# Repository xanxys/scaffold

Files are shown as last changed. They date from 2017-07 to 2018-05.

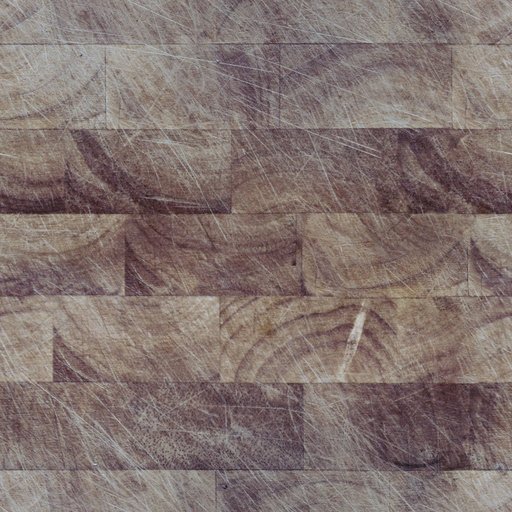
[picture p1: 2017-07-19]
overmind/texture/wood.jpg

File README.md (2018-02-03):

# scaffold

Scaffold: Progression of Rails 2017 (https://www.youtube.com/watch?v=H0F9yggMfn8 "Scaffold: Progression of Rails 2017")

* PRD: https://docs.google.com/document/d/1AyhhH3LTPeGcEkzU2smBuM1e6MzfZJXZTJ8Jl38s1jc/edit
* Designs
  * Mechanical hardware: Autodesk Fusion360 cloud
  * Electronic hardware: Google Drive / Eagle
  * Firmware: This repo
  * Softawre: This repo (`overmind/`)
* Experiments
  * TBD
* Documents: https://drive.google.com/drive/folders/0B6zCoyeuDn-pVGp6S2Y4Tmo1dEE

## Components

* worker: AVR firmware for worker PCB
* feeder: AVR firmware for rail feeder
* overmind: controls everything, via TWELITE monostick. Written in electron (desktop webapp platform).

Model names:

https://docs.google.com/document/d/1zPHIgSu1AZrwIe-akWDu8TK5ug4Fznx-tUY5lZn-zfI/edit?usp=drive_web

## Overmind

First-time only, when you cloned repo, run:
```
cd ./overmind
npm install
```

To develop / run overmind, you need two consoles.

In one, do the following to compile & setup dynamic reloader for
```
cd ./overmind
npm run dev
```

Then, in another, to start the app:
```
cd ./overmind
npm start
```

To run unit tests:
```
npm test
```

## Requirements

Re-creating

* SLA 3d printing: Form2
* PWB manufacturer: Seeed studio
* Electronic parts: All are sourceabe from digikey
* PCB reflow oven
* USBasp

## AVR Firmware writing

First time only:
```
scons writefuse
```

First time & whenever code is changed:
```
scons write-builder
```
or
```
scons write-feeder
```

Just compile and see resulting FW size:
```
scons
```

# Communication Protocol Stack

## Commands

* p: print status
* e: enqueue actions

```
Command
  = "p"
  | "e" Action+
```

```
Action = [Duration ms : 2] ([ActionTarget ASCII: 1] [ActionVal int : 1]*)*
```

e.g.
```
eA123BCD-23
```

## Addressing

Everything is in big endian.

overmind -> worker
```
Packet = [dest addr : 4] Command
```
When addr = 0xffffffff, it means broadcasting.

worker -> overmind
```
Packet = [src addr : 4] [worker timestamp in millisec : 4] [JSON ascii : N]
```

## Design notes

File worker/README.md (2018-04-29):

# Worker (Builder 2.0: S60C-TB, Feeder 1.0: S60C-FD-x)

Builder 2.0
* PCB DD & Eratta: https://docs.google.com/document/d/1Juym4ehH7gGHqDHJOSv_l-aBb0Xs5iWDp3gg6BylRzI/edit
* Designs
  * Hardware: Autodesk Fusion360 cloud
  * PCB: Eagle
    * 2.0: https://drive.google.com/file/d/0B6zCoyeuDn-pWUhYQTVqWkgwS1E/view?usp=sharing

Feeder 1.0

## Error Handling Policy

* Discrete data (command type): Ignore & warn
* Analog data (duration, pos, vel): Clip & warn

## Coordinate System

S60-TB

|Canonical | IMU |
|---|---|
| X | -Y |
| Y | X |
| Z | Z |

## Sensor Commands & Pins

|New name|ADC pin| Legacy Name | TB | FDW-RS | TB legacy commands | FDW-RS legacy commands |
|---|---|---|---|---|---|---|
| S0 | 1 |  T | rail center (+)  | port stops (-) | Tx: if S0>=x, stop MV0 | Sx: if S0<x, stop MV0 |
| S1 | 6 |  O | unused | origin (+) | | Ox: if S1>x, stop MV0 |
| S2 | 7 |  X | unused | unused | | |

polarities

* + (value is big when condition is true)
* - (value is smaller whencondition is true)

In the new scheme, polarity is baked as FW and value is negated (x := 255-x) in the worker.
Thus, only S(n)>x: stop MV(0) cutoff condition is necessary.

This command is written as "/S0>12", "/S1>200" etc in human-readable command format.
Zero or one condition can exist in an Action.

## Action human & binary format

Human readable action format:

```
Command = 'e' Action (',' Action)*

Action = (dur:Integer[1,5000]) (Target Value)+ CutoffCondition?

Target
  = 'a' | 'b'  # BT SRV
  | 't' | 'o' | 's'  # BT MV
  | 'v'  # FDW-RS MV

CutoffCondition = '/' 'S' (sensor_index:Integer[0,2]) '>' (sensor_value:Value)

Value = Integer[0, 255]
```

Binary action format:

```
Command = 'e' (num_actions: Uint8) Action+

Action = (dur:Uint16be) (numTVs:Uint7) (numCutoff:Uint1) (Target:Uint8 value:Uint8)+ CutoffCondition?

CutoffCondition = (sensor_index:Uint8) (sensor_value:Uint8)
```

## Builder Pin assigment / connections (V2)
ATmega328P

16MHz (ceralock) / 1:1 clock division / No watchdog

|pin|usage|
|---|---|
|PB0| - |
|PB1| - |
|PB2| - |
|PB3/OC2A| ISP MOSI / PWMA  |
|PB4| ISP MISO  |
|PB5| ISP SCK  |
|PB6| XTAL1  |
|PB7| XTAL2  |
| |  |
| |  |
|PC0| red indicator LED  |
|PC1/ADC1| SEN-T  |
|PC2| -  |
|PC3| -  |
|PC4| I2C-SDA  |
|PC5| I2C-SCL  |
|PC6| #RESET  |
|PC7| -  |
| |  |
| |  |
|ADC6| SEN-O (rail marker)  |
|ADC7| Rail Sensor  |
| |  |
| |  |
|PD0| TWELITE-RX  |
|PD1| TWELITE-TX  |
|PD2| -  |
|PD3/OC2B| PWMB  |
|PD4| - |
|PD5| - |
|PD6| - |
|PD7| - |

### Extension head

A(right): screw rack

B(left): dump

### I2C bus

DRV8830 (1/3)

* OUT: Train motor
* Addr[3:0]: 0000 (A0: L, A1: L)

DRV8830 (2/3)

* OUT: Orientor motor
* Addr[3:0]: 0001 (A0: open, A1: L)

DRV8830 (3/3)

* OUT: Extension motor (screw)
* Addr[3:0]: 0010 (A0: H, A1: L)

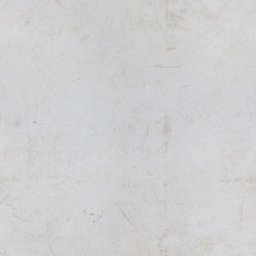
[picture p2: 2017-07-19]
overmind/texture/plastic.jpg

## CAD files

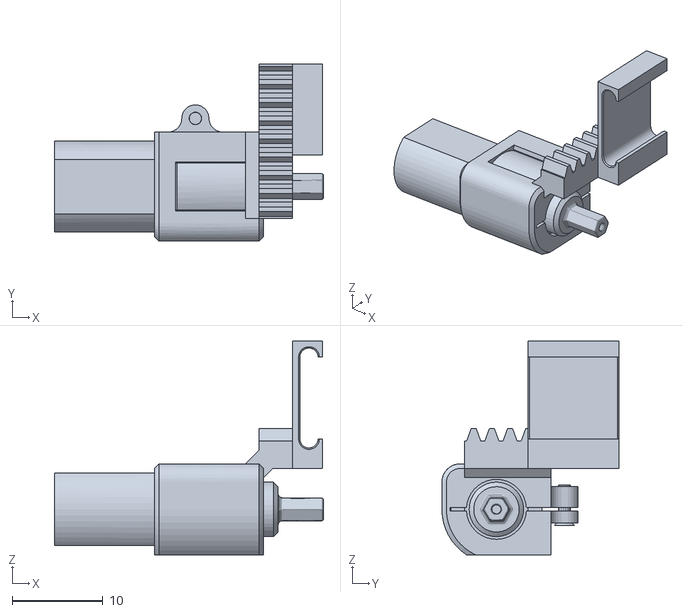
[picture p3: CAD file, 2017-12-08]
overmind/models/S60C-TB_mhead.stl
29.6 x 19.5 x 23.5

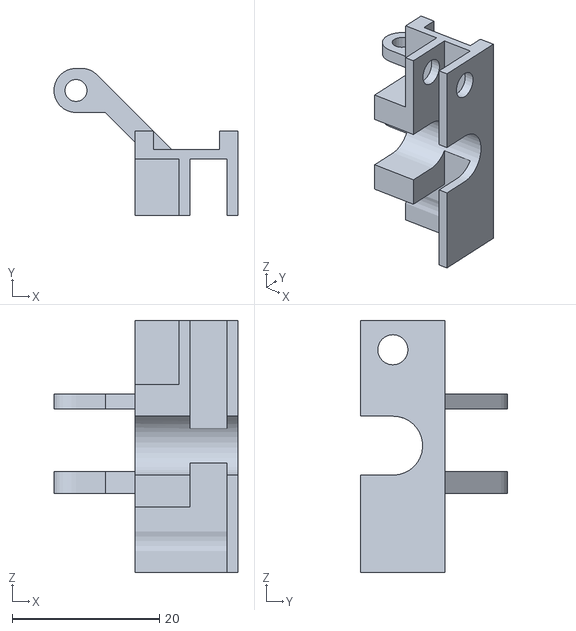
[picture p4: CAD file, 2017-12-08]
overmind/models/S60C-TB_darm.stl
25.0 x 20.0 x 34.2

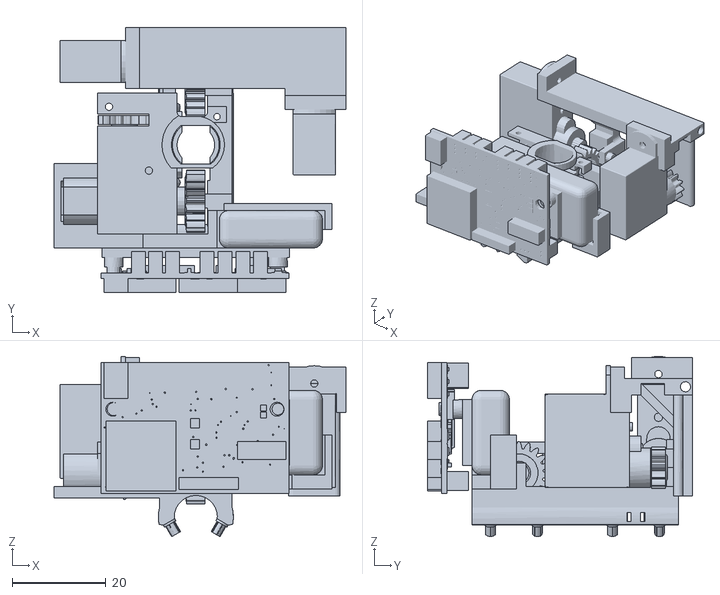
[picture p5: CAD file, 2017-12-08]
overmind/models/S60C-TB.stl
62.2 x 56.5 x 38.5

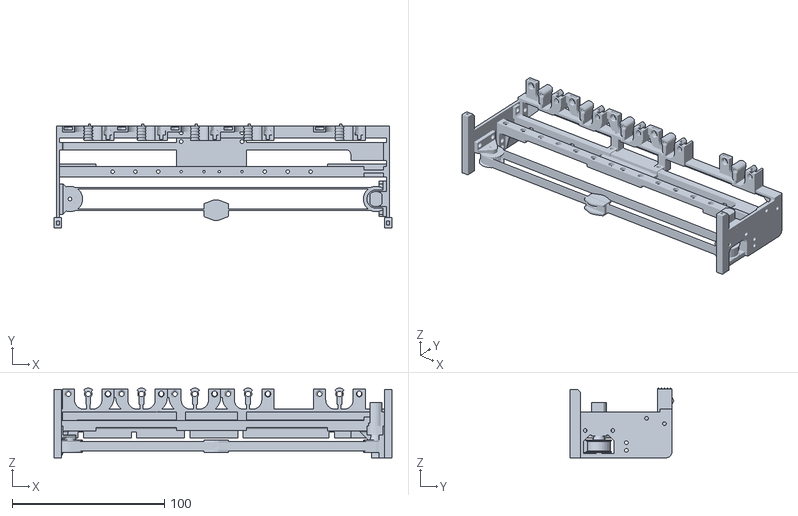
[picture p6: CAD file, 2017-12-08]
overmind/models/S60C-FDW-RS_fixed.stl
222.0 x 68.2 x 45.9

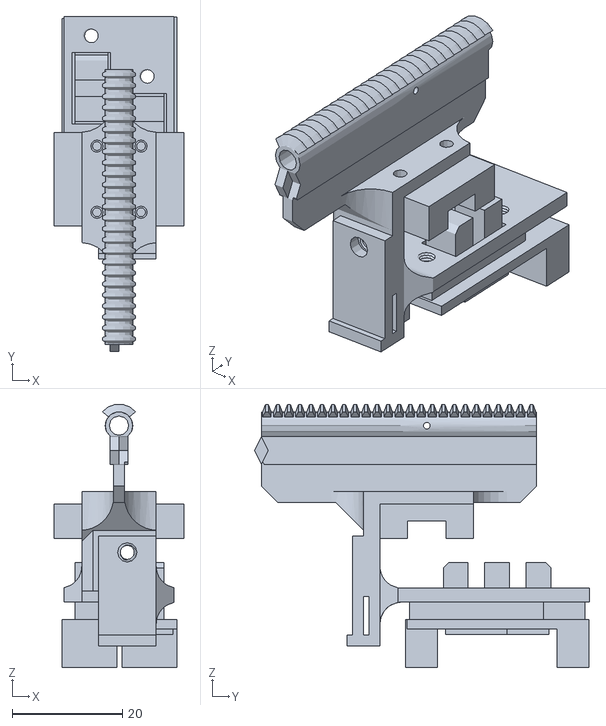
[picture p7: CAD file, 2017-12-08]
overmind/models/S60C-FDW-RS_stage.stl
23.5 x 60.8 x 47.7

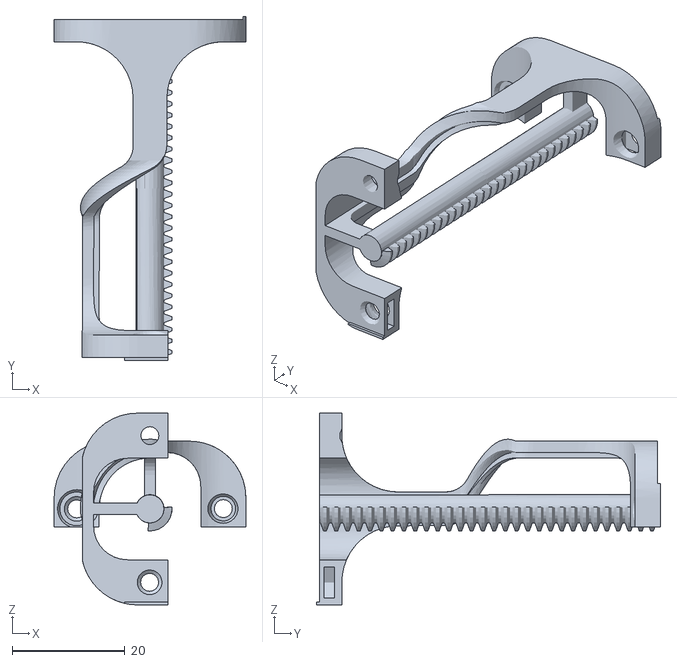
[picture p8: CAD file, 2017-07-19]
overmind/models/S60C-RH.stl
34.0 x 61.0 x 34.0

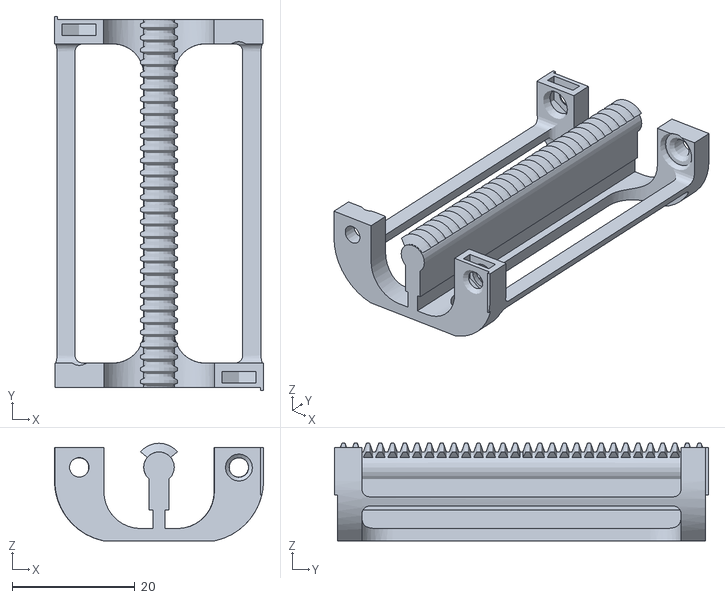
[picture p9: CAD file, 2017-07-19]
overmind/models/S60C-RS.stl
34.0 x 61.0 x 15.9

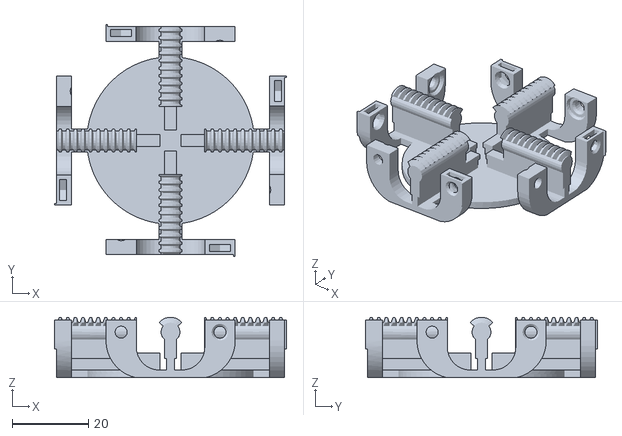
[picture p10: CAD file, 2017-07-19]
overmind/models/S60C-RR.stl
61.0 x 61.0 x 15.9

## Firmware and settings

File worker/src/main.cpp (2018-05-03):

#include <Arduino.h>
#include <MsTimer2.h>
#include <nanopb/pb_decode.h>
#include <nanopb/pb_encode.h>
#include <proto/builder.pb.h>

#include "action.hpp"
#include "shared_state.h"

ActionExecutorSingleton g_actions;

int16_t convert_acc(int16_t raw) {
  return (static_cast<int32_t>(raw) * 61) / 1000;
}

void fill_sensor_status(SensorStatus& status) {
  // TODO: scaling
  status.gyro_x_cdps = -imu.gyro[1];
  status.gyro_y_cdps = imu.gyro[0];
  status.gyro_z_cdps = imu.gyro[2];

  // status.acc_x_mg = convert_acc(-imu.acc[1]);
  // status.acc_y_mg = convert_acc(imu.acc[0]);
  // status.acc_z_mg = convert_acc(imu.acc[2]);
  status.acc_x_mg = odometry.vx;
 // status.acc_y_mg = odometry.rot;
  status.acc_z_mg = 0;

  status.optical_rail = sensor.get_sensor2();
  status.odometry_rail = odometry.get_rot();
}

class CommandHandler {
 private:
  MaybeSlice datagram;  // dependent on buffer inside twelite.
  int r_ix;

  uint8_t buffer[80];

 public:
  CommandHandler(MaybeSlice datagram) : datagram(datagram), r_ix(0) {}

  void handle() {
    r_ix = 0;
    indicator.flash_blocking();
    uint8_t code = read();
    switch (code) {
      case CommandType_PRINT_STATUS:
        exec_print();
        break;
      case CommandType_SCAN_I2C:
        exec_scan();
        break;
      case CommandType_ENQUEUE:
        exec_enqueue();
        break;
      case CommandType_READ_SENSOR:
        exec_read_sensor();
        break;
      default:
        TWELITE_ERROR(Cause_OVERMIND);  // unknown command
        break;
    }
  }

 private:
  // Consume next byte if it matches target (return true).
  // If it doesn't match, doesn't consume anything (return false).
  bool consume(char target) {
    if (r_ix < datagram.size) {
      if (datagram.ptr[r_ix] == target) {
        r_ix++;
        return true;
      }
    }
    return false;
  }

  char peek() {
    if (r_ix < datagram.size) {
      return datagram.ptr[r_ix];
    } else {
      return 0;
    }
  }

  bool available() { return r_ix < datagram.size; }

  char read() {
    if (r_ix < datagram.size) {
      char ret = datagram.ptr[r_ix];
      r_ix++;
      return ret;
    } else {
      return 0;
    }
  }

  void unread(char c) {
    if (r_ix > 0) {
      r_ix--;
    }
  }

  int16_t parse_int() {
    bool positive = !consume('-');
    int16_t v = 0;
    while (available()) {
      char c = read();
      if ('0' <= c && c <= '9') {
        v = v * 10 + (c - '0');
      } else {
        unread(c);
        break;
      }
    }
    return positive ? v : -v;
  }

 private:  // Command Handler
  void exec_enqueue() {
    while (true) {
      enqueue_single_action();
      if (!consume(',')) {
        break;
      }
    }
    TWELITE_INFO();  // Enqueue executed.
  }

  void exec_print() {
    {
      Status status;
      g_actions.fill_status(status);

      buffer[0] = PacketType_STATUS;
      pb_ostream_t stream =
          pb_ostream_from_buffer((pb_byte_t*)(buffer + 1), sizeof(buffer) - 1);
      if (pb_encode(&stream, Status_fields, &status)) {
        twelite.send_datagram(buffer, 1 + stream.bytes_written);
      } else {
        TWELITE_ERROR(Cause_LOGIC_RT);
      }
    }
    delay(10);
    {
      IOStatus status;
      fill_io_status(status);

      buffer[0] = PacketType_IO_STATUS;
      pb_ostream_t stream =
          pb_ostream_from_buffer((pb_byte_t*)(buffer + 1), sizeof(buffer) - 1);
      if (pb_encode(&stream, IOStatus_fields, &status)) {
        twelite.send_datagram(buffer, 1 + stream.bytes_written);
      } else {
        TWELITE_ERROR(Cause_LOGIC_RT);
      }
    }
  }

  void exec_read_sensor() {
    ReadSensorCommand command;
    pb_istream_t stream =
        pb_istream_from_buffer(datagram.ptr + 1, datagram.size - 1);
    if (!pb_decode(&stream, ReadSensorCommand_fields, &command)) {
      TWELITE_ERROR(Cause_OVERMIND);  // unparsable
      return;
    }

    // TODO: Read value.
    g_async_sensor_ttl_ms = 5000;  // command.verbose_sensor_ttl_ms;
    g_async_sensor_since_last_sent_ms = 0;
  }

  void exec_scan() {
    I2CScanResult result;
    g_actions.fill_i2c_scan_result(result);

    buffer[0] = PacketType_I2C_SCAN_RESULT;
    pb_ostream_t stream =
        pb_ostream_from_buffer((pb_byte_t*)(buffer + 1), sizeof(buffer) - 1);
    if (pb_encode(&stream, I2CScanResult_fields, &result)) {
      twelite.send_datagram(buffer, 1 + stream.bytes_written);
    } else {
      TWELITE_ERROR(Cause_LOGIC_RT);
    }
  }

  void enqueue_single_action() {
    int16_t dur_ms = parse_int();
    if (dur_ms < 1) {
      dur_ms = 1;
      TWELITE_ERROR(Cause_OVERMIND);  // dur capped to 1ms
    } else if (dur_ms > 5000) {
      dur_ms = 5000;
      TWELITE_ERROR(Cause_OVERMIND);  // dur capped to 5s
    }
    Action action(dur_ms);

    while (true) {
      char target = read();
      switch (target) {
        case '!':
          // action.report = true;
          break;
        case 'a':
          action.servo_pos[CIX_A] = safe_read_pos();
          break;
        case 'b':
          action.servo_pos[CIX_B] = safe_read_pos();
          break;
        case 't':
          action.motor_vel[MV_TRAIN] = safe_read_vel();
          break;
        case 'o':
          action.motor_vel[MV_ORI] = safe_read_vel();
          break;
        case 's':
          action.motor_vel[MV_SCREW_DRIVER] = safe_read_vel();
          break;
        case 'T':
          action.train_cutoff_thresh = safe_read_thresh();
          break;
        default:
          TWELITE_ERROR(Cause_OVERMIND);  // unknown action target
      }

      char next = peek();
      if (next == 0 || next == ',') {
        break;
      }
    }
    g_actions.enqueue(action);
  }

  uint8_t safe_read_thresh() {
    int16_t value = parse_int();
    if (value < 0) {
      value = 0;
      TWELITE_ERROR(Cause_OVERMIND);  // too small value
    } else if (value > 255) {
      value = 255;
      TWELITE_ERROR(Cause_OVERMIND);  // too big value
    }
    return value;
  }

  uint8_t safe_read_pos() {
    int16_t value = parse_int();
    if (value < 10) {
      value = 10;
      TWELITE_ERROR(Cause_OVERMIND);  // too small pos
    } else if (value > 33) {
      // note: 255 is reserved as SERVO_POS_KEEP.
      value = 33;
      TWELITE_ERROR(Cause_OVERMIND);  // too big pos
    }
    return value;
  }

  int8_t safe_read_vel() {
    int16_t value = parse_int();
    if (value < -127) {
      value = -127;
      TWELITE_ERROR(Cause_OVERMIND);  // too small vel
    } else if (value > 127) {
      value = 127;
      TWELITE_ERROR(Cause_OVERMIND);  // too big vel
    }
    return value;
  }

  void fill_io_status(IOStatus& status) const {
    fill_sensor_status(status.sensor);
    g_actions.fill_output_status(status.output);
  }
};

constexpr uint8_t IMU_POLL_CYCLE = 19;
uint8_t imu_poll_index = 0;

void loop1ms() {
  g_actions.loop1ms();

  uint16_t ttl_ms = g_async_sensor_ttl_ms;
  if (ttl_ms > 0) {
    ttl_ms--;
  }
  g_async_sensor_ttl_ms = ttl_ms;
  g_async_sensor_since_last_sent_ms++;

  if (imu_poll_index == 0) {
    imu.poll();
    odometry.poll();
  }
  imu_poll_index++;
  if (imu_poll_index >= IMU_POLL_CYCLE) {
    imu_poll_index = 0;
  }
}

int main() {
  //// Minimum AVR & 3.3V (TWELITE) init.
  // Init arduino core things (e.g. Timer0).
  init();
  twelite.init();
  indicator.flash_blocking();
  TWELITE_INFO();  // Minimum HW initialized.

  //// Enable 5V & peripherals.
  set_5v_power(true);
  delay(50);  // IMU(20ms), 5V DC/DC (?ms)

  // Init I2C bus.
  I2c.begin();
  I2c.pullup(0);  // we use external pullup registers
  I2c.timeOut(10);

  // Start 6-axis sensor.
  imu.init();

  // Start odometry magnetic sensor.
  odometry.init();

  indicator.flash_blocking();
  TWELITE_INFO();  // All HW initialized.

  g_actions.init();
  // Initialize servo pos to safe (i.e. not colliding with rail) position.
  {
    Action action(1 /* dur_ms */);
    action.servo_pos[CIX_A] = 13;
    action.servo_pos[CIX_B] = 11;
    g_actions.enqueue(action);
  }

  // Fully initialized. Start realtime periodic process & idle tasks.
  setMillisHook(loop1ms);
  while (true) {
    if (g_twelite_packet_recv_done) {
      MaybeSlice datagram = twelite.get_datagram();
      if (datagram.is_valid()) {
        CommandHandler command_handler(datagram);
        command_handler.handle();
      }
      twelite.restart_recv();
    }
    if (g_async_message_avail) {
    }
    if (g_async_sensor_ttl_ms > 0 && g_async_sensor_since_last_sent_ms > 100) {
      IOStatus status;
      status.output = OutputStatus_init_default;
      fill_sensor_status(status.sensor);

      uint8_t buffer[80];
      buffer[0] = PacketType_IO_STATUS;
      pb_ostream_t stream =
          pb_ostream_from_buffer((pb_byte_t*)(buffer + 1), sizeof(buffer) - 1);
      if (pb_encode(&stream, IOStatus_fields, &status)) {
        twelite.send_datagram(buffer, 1 + stream.bytes_written);
      } else {
        TWELITE_ERROR(Cause_LOGIC_RT);
      }

      g_async_sensor_since_last_sent_ms = 0;
    }
  }
}

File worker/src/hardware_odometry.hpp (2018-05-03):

#pragma once

#include <I2C.h>

/**
 * Driver for MLX90393 magnetic sensor, which is coupled to measure main axis
 * gear rotation. ds:
 * https://cdn.sparkfun.com/assets/learn_tutorials/5/7/7/MLX90393-Datasheet-Melexis.PDF
 *
 * sample code:
 * https://github.com/ControlEverythingCommunity/MLX90393/blob/master/Arduino/MLX90393.ino
 */
class Odometry {
 private:
  constexpr static uint8_t addr =
      20;  // designed to be 0x0c, but somehow ended up being 20.

  // Commands
  constexpr static uint8_t WRITE_REGISTER = 0x60;

  constexpr static uint8_t STATUS_BURST_MODE = _BV(7);
  constexpr static uint8_t STATUS_ERROR = _BV(4);

  struct __attribute__((__packed__)) U16Be {
    uint8_t h;
    uint8_t l;
  };

  struct __attribute__((__packed__)) ReadMeasurementResult {
    uint8_t status;
    U16Be x, y, z;
  };

  /**
   * These constants are generated by following python code:
   *
   * COS: python -c "import math; print [int(math.cos(i/128.0*math.pi)*255) for
   * i in range(64)]" SIN: python -c "import math; print
   * [int(math.sin(i/128.0*math.pi)*255) for i in range(64)]"
   */
  static constexpr uint8_t QUAD_ANGLE = 64;
  const uint8_t QUAD_COS[QUAD_ANGLE] = {
      255, 254, 254, 254, 253, 253, 252, 251, 250, 248, 247, 245, 244,
      242, 240, 237, 235, 233, 230, 227, 224, 221, 218, 215, 212, 208,
      204, 201, 197, 193, 188, 184, 180, 175, 171, 166, 161, 156, 151,
      146, 141, 136, 131, 125, 120, 114, 109, 103, 97,  91,  85,  79,
      74,  68,  61,  55,  49,  43,  37,  31,  24,  18,  12,  6};

  const uint8_t QUAD_SIN[QUAD_ANGLE] = {
      0,   6,   12,  18,  24,  31,  37,  43,  49,  55,  61,  68,  74,
      79,  85,  91,  97,  103, 109, 114, 120, 125, 131, 136, 141, 146,
      151, 156, 161, 166, 171, 175, 180, 184, 188, 193, 197, 201, 204,
      208, 212, 215, 218, 221, 224, 227, 230, 233, 235, 237, 240, 242,
      244, 245, 247, 248, 250, 251, 252, 253, 253, 254, 254, 254};

 public:
  bool init_success = false;
  int16_t vx = 0;
  int16_t vy = 0;

  // As seen from X+, CCW is positive (=forward)
  uint8_t angle = 0;
  int8_t num_rot = 0;

  void init() {
    // Reset command.
    // I2c.write(addr, (uint8_t)0xf0);
    // delay(10);

    // Set RES{x,y,z} = 2, OSR=0, DIG_FILT=0
    write_reg(2, 0b101010 << 5);

    // COMM_MODE=I2C (0b11), BURST_DATE_RATE=1
    write_reg(1, (0b11 << 13) | 1);

    // GAIN=5, HALL_PLATE=0xc (default)
    write_reg(0, 0x5c);

    // Enter "Burst Mode", with measurement in all magnetic channels (Z, Y, X).
    //  I2c.write(addr, (uint8_t)0x1e);
    init_success = true;
    return;

    uint8_t status;
    uint8_t code = I2c.read(addr, 0x1e, (uint8_t)1, &status);
    vx = status + 1000;

    if ((status & STATUS_BURST_MODE) && !(status & STATUS_ERROR)) {
      init_success = true;
    }
  }

  void poll() {
    if (!init_success) {
      return;
    }
    uint8_t status;
    uint8_t code = I2c.read(addr, 0x3e, (uint8_t)1, &status);
    if (code != 0) {
      vx = 1000 + code;
      return;
    }
    if (status & STATUS_ERROR) {
      vx = 2000 + status;
      return;
    }
    delay(100);

    // Read measurement command
    I2c.write(addr, (uint8_t)0x4e);

    ReadMeasurementResult result;
    code = I2c.read(addr, 7, reinterpret_cast<uint8_t*>(&result));
    if (code != 0) {
      vx = 3000 + code;
      return;
    }
    if (result.status & STATUS_ERROR) {
      vx = 4000 + result.status;
      return;
    }
    // Expecting 6B data. -> must be 2 (2x2 + 2 = 6)
    if (result.status & 3 != 2) {
      vx = 5001;
      return;
    }
    vx = decode_value(result.x);
    vy = decode_value(result.y);
    const uint8_t new_angle = 256 - atan2(vx >> 8, vy >> 8);  // convert from sensor coords to human coords.
    const uint8_t delta = new_angle - angle;
    if (delta < 128) {
      // real angle increased
      if (new_angle < angle) {
        num_rot++;  // overflown
      }
    } else {
      // real angle decreased
      if (new_angle > angle) {
        num_rot--;  // underflown
      }
    }
    angle = new_angle;
  }

  int16_t get_rot() const { return ((int16_t)num_rot) * 256 + angle; }

 private:
  void write_reg(uint8_t mem_addr, uint16_t val) {
    uint8_t command[3];
    command[0] = val >> 8;
    command[1] = val & 0xff;
    command[2] = mem_addr << 2;
    I2c.write(addr, WRITE_REGISTER, command, (uint8_t)sizeof(command));

    uint8_t status;
    I2c.read(addr, 1, &status);
  }

  int16_t decode_value(const U16Be& v) {
    uint16_t temp = (((uint16_t)v.h) << 8) + v.l;
    if (temp > 0x8000) {
      return temp - 0x8000;
    } else {
      return -(0x8000 - temp);
    }
  }

  // Returns angle of vector (x, y), in [0, 256).
  // angle will be down-rounded.
  uint8_t atan2(int8_t x, int8_t y) const {
    if (y >= 0) {
      return x >= 0 ? atan2_quad(x, y) : atan2_quad(y, -x) + QUAD_ANGLE;
    } else {
      return x >= 0 ? (atan2_quad(-y, x) + QUAD_ANGLE * 3)
                    : (atan2_quad(-x, -y) + QUAD_ANGLE * 2);
    }
  }
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

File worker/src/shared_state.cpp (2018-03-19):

#include "shared_state.h"

Indicator indicator;
TweliteInterface twelite;
IMU imu;
DCMotor motor_screw(98);
MultiplexedSensor sensor;
Odometry odometry;

volatile bool g_twelite_packet_recv_done = false;
volatile bool g_async_message_avail = false;
volatile uint16_t g_async_sensor_ttl_ms = 0;
volatile uint16_t g_async_sensor_since_last_sent_ms = 0;

void set_5v_power(bool enabled) {
  const uint8_t EN5V = _BV(0);

  if (enabled) {
    PORTB |= EN5V;
  } else {
    PORTB &= ~EN5V;
  }
}

Indicator::Indicator() { DDRC |= _BV(PC0); }

void Indicator::flash_blocking() {
  PORTC |= _BV(PC0);
  delay(50);
  PORTC &= ~_BV(PC0);
  apply_error();
}

void Indicator::enter_error() {
  error = true;
  apply_error();
}

void Indicator::apply_error() {
  if (error) {
    PORTC |= _BV(PC0);
  } else {
    PORTC &= ~_BV(PC0);
  }
}

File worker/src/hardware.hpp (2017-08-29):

#pragma once
/* Hardware usage
* Timer0: system clock
* Timer1: action loop
* Timer2: Servo PWM
*/

#include <stdint.h>

#include "hardware_twelite.hpp"


class Indicator {
private:
  bool error;
public:
  Indicator() {
    DDRC |= _BV(PC0);
  }

  void flash_blocking() {
    PORTC |= _BV(PC0);
    delay(50);
    PORTC &= ~_BV(PC0);
    apply_error();
  }

  void enter_error() {
    error = true;
    apply_error();
  }
private:
  void apply_error() {
    if (error) {
      PORTC |= _BV(PC0);
    } else {
      PORTC &= ~_BV(PC0);
    }
  }
};

Indicator indicator;

// Perodically measure fixed number of ADC inputs & controls sensor multiplexing.
// Each phase is 2ms.
//
class MultiplexedSensor {
private:
  // Sensor channels.
  static const uint8_t I_BAT = 2;
  static const uint8_t I_SEN_T = 1;
  static const uint8_t I_SEN_O = 6;
  static const uint8_t I_SEN_X = 7;
  static const uint8_t I_INTERNAL_1V1REF = _BV(MUX3) | _BV(MUX2) | _BV(MUX1);

  // Phase definitions.
  const static uint8_t PHASE_SEN_T = 0;
  const static uint8_t PHASE_SEN_O = 1;
  const static uint8_t PHASE_SEN_X = 2;
  const static uint8_t PHASE_AVCC = 3;
  const static uint8_t PHASE_BAT = 4;
  const static uint8_t NUM_PHASES = 5;

  uint8_t current_phase;
  uint8_t phase_index;
  const static uint8_t phase_length = 2;

  uint16_t value_cache[NUM_PHASES];
public:
  MultiplexedSensor() : current_phase(PHASE_SEN_T), phase_index(0) {
  }

  void loop1ms() {
    phase_index++;
    if (phase_index == 1) {
      on_phase_middle();
    } else if (phase_index >= phase_length) {
      on_phase_end();

      phase_index = 0;
      current_phase = (current_phase + 1) % NUM_PHASES;
      on_phase_begin();
    }
  }

  // 0: 0V, 255: 5V ("max")
  uint8_t get_sensor_t() const {
    return value_cache[PHASE_SEN_T] >> 2;
  }

  uint8_t get_sensor_o() const {
    return value_cache[PHASE_SEN_O] >> 2;
  }

  uint8_t get_sensor_x() const {
    return value_cache[PHASE_SEN_X] >> 2;
  }

  uint16_t get_bat_mv() const {
    uint32_t t = value_cache[PHASE_BAT] * 5000L;
    t /= 1024L;
    return t;
  }

  uint16_t get_vcc_mv() const {
    uint32_t result = value_cache[PHASE_AVCC];
    result = (1024L * 1100L) / result; // Back-calculate AVcc in mV
    return result;
  }

  uint8_t get_rate_ms() const {
    return NUM_PHASES * phase_length;
  }

  bool is_start() const {
    return phase_index == 0 && current_phase == 0;
  }
private:
  void on_phase_begin() {
    // Connect AVcc to Vref.
    ADMUX = _BV(REFS0);

    switch (current_phase) {
      case PHASE_SEN_T:
        ADMUX |= I_SEN_T;
        break;
      case PHASE_SEN_O:
        ADMUX |= I_SEN_O;
        break;
      case PHASE_SEN_X:
        ADMUX |= I_SEN_X;
        break;
      case PHASE_AVCC:
        ADMUX |= I_INTERNAL_1V1REF;
      case PHASE_BAT:
        ADMUX |= I_BAT;
        break;
    }
  }

  void on_phase_middle() {
    // Start AD conversion.
    ADCSRA |= _BV(ADSC);
  }

  void on_phase_end() {
    if (!bit_is_set(ADCSRA, ADSC)) {
      // ADCL needs to be read first to ensure consistency.
      value_cache[current_phase] = ADCL;
      value_cache[current_phase] |= ADCH << 8;
    }
  }
};

class DCMotor {
private:
  // 7-bit address (common for read & write, MSB is 0)
  const uint8_t i2c_addr7b;
public:
  DCMotor(uint8_t i2c_addr) : i2c_addr7b(i2c_addr >> 1) {
  }

  void set_velocity(int8_t speed) {
    uint8_t abs_speed = (speed > 0) ? speed : (-speed);
    uint8_t value;
    if (abs_speed < 3) {  // 1,2 corresponds to RESERVED VSET value.
      value = 3;  // brake
    } else {
      value = (speed > 0) ? 2 : 1;  // fwd : bwd

      // abs_speed: 0sss ssss
      // value: ssss ssXX (XX=direction)
      value |= ((abs_speed << 1) & 0xfc);  // adjust scale & throw away lower 2 bits
    }

    sei();  // w/o this, TWI gets stuck after sending start condtion.
    Wire.beginTransmission(i2c_addr7b);
    Wire.write(0);  // CONTROL register
    Wire.write((byte)value);
    uint8_t res = Wire.endTransmission();
    cli();

    if (res != 0) {
      indicator.enter_error();
      twelite.warn("I2C failed");
    }
  }
};

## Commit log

2017-04-25 Please arduino ide.
2017-04-27 Queue print command.
2017-04-28 Fix very short action. Much better queue printing.
2017-04-28 Fix KEEP printing.
2017-04-29 Implement own servo / DC PWM to ix jumpiness of Servo.write output duty ratio.
2017-04-29 Fix DC motor CCW & stop.
2017-04-29 Fix PWM
2017-04-29 Adjust servo initial pos.
2017-05-04 Update pin assignment for servos.
2017-05-05 Add pin assignments to README.
2017-05-05 Rewrite DC motors to use I2C instead of timer-based PWM.
2017-05-05 Fix i2c speed & address.
2017-05-05 Add I2C result check.
2017-05-05 Add sensor read command (r).
2017-05-05 Fix servo pin assignment.
2017-05-06 Swap servo indices to match physical layer.
2017-05-21 Make things compilable without arduino IDE.
2017-05-21 Add command to write fuse for 16MHz.
2017-05-21 Update pin assignments.
2017-05-21 Add arduino initializer and LED ticking test.
2017-05-28 Half-duplex command proxy. DC motors working.
2017-05-28 Better pin table
2017-06-06 Add hack to reduce servo vibration at stasis. (to about 20% of cases, from 90%+)
    [action.hpp, hardware.hpp, main.cpp]
2017-06-06 Fundametally fix servo vibration by reducing PWM frequency.
    [action.hpp, main.cpp]
2017-06-17 Fix initial servo position.
    [action.hpp, main.cpp]
2017-06-17 Shorthand commands for extending.
    [main.cpp]
2017-06-18 Remove legacy arduino worker.
2017-06-18 Command for unfastening. Fix driver disengage (z5).
    [main.cpp]
2017-06-18 Richer status including voltage & uptime.
2017-06-20 Add pins for sensor illuminator
2017-06-21 Sensor alternating illuminators
2017-06-21 Sensor multipler. Readouts are working as intended on the rail.
2017-06-22 Delte no longer working read sensor command.
    [main.cpp]
2017-06-24 Increase driver pull robusetness.
2017-07-19 Mock overmind UI for left pane.
    [S60C-RH.stl, S60C-RR.stl, S60C-RS.stl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]
2017-07-19 Add scaffold CAD model loaders.
2017-07-19 Rail extension mock.
2017-08-06 Fix arduino header path (for Fedora26)
2017-08-06 Update pin assignments for V2.
2017-08-06 Use native PWM in V2.
2017-08-08 Succesful bidir wireless comm.
2017-08-11 Fix some leftover command validator.
    [main.cpp]
2017-08-12 Fix PWMA init
2017-08-12 Set emprically determined servo PWM range.
2017-08-13 Stabilize servos by increasing duration.
    [action.hpp, main.cpp]
2017-08-13 Update sensors to reflect new mapping & include BAT measurement.
2017-08-17 Fix loop freq & DM index.
    [main.cpp]
2017-08-17 Work around I2C address change for S-axis.
2017-08-19 Remove checksum correctly when parsing command.
    [main.cpp]
2017-08-27 Add sensor reading reporting.
2017-08-28 Fix async reporting & remove concept of step and always ms as time unit.
    [action.hpp, main.cpp]
2017-08-28 Show sensor measured values as line graph.
2017-08-29 Implement sensor finding action.
2017-08-29 Fix broken cache log. Remove hack to determine payload type.
    [action.hpp, main.cpp]
2017-08-29 Fix parse_int bug that accidentally appends 0.
    [main.cpp]
2017-08-29 Add find origin button.
2017-08-29 Don't print succesful messages.
2017-08-29 Add battery indicator.
2017-08-29 Fix / handle command buffer overflow properly.
    [main.cpp]
2017-08-29 Pretty stable extend/shorten ops with single button click.
    [action.hpp, main.cpp]
2017-09-01 Panel switching with animation.
2017-09-02 Fix unique id retrieval.
    [main.cpp]
2017-09-03 Freeup timer1
2017-09-03 Add material card finish.
2017-09-09 Update feeder pin assignmnet doc.
2017-09-09 Support stepper motor in feeder.
2017-09-20 Add sensor reactive command V to feeder FW.
2017-09-20 Implement R/C-axis in fedder and provide UI buttons.
2017-09-23 Fix spacing in multi-card case.
2017-10-12 Cleanup worker card command buttons.
2017-10-15 Fix button interferences.
2017-11-19 Add FDW-RS model.
    [S60C-FDW-RS.stl]
2017-11-19 Fix FDW CAD model alignment.
2017-11-20 Support all rail types.
2017-11-21 Fix WorldView buttons.
2017-11-30 Implement remove rail button
2017-12-04 Fix timestamp N/A & sensor reading graphs
2017-12-07 Use orthographic camera
2017-12-08 Replace FDW-RS with composite models
    [S60C-FDW-RS.stl, S60C-FDW-RS_fixed.stl, S60C-FDW-RS_stage.stl]
2017-12-08 Add S60C-TB composite model
    [S60C-TB_darm.stl, S60C-TB_fixed.stl, S60C-TB_mhead.stl]
2017-12-09 Move STL loading from view to ScaffoldModel
    [S60C-FDW-RS.stl, S60C-T.stl, S60C-TB.stl]
2017-12-10 Update FD firmware to support two sensors
2017-12-10 Fix sensor commands for FDW-RS
    [action.hpp, main.cpp]
2017-12-10 Update sensor status message
2017-12-10 Put succesful twice. HW modif: Extend DRV & Rotate DARM SERVO CCW (seen from left) and fix tightly
2017-12-11 Add show future button
2017-12-11 Fix semantics of model init button
2017-12-11 Implement ScaffoldModel switching
2017-12-17 "Fix" setTimeout -> Timer cast
2017-12-17 Refine TB commands according to 6mm driver
2017-12-17 Fix FDW-RS param-stagePos bidir mapping
2017-12-18 Fix stage anim
2017-12-20 FDW-RS stagePos editing
2017-12-20 Couple TB to FDW stage
2018-02-04 Use better I2C library
2018-02-04 I2C bus scanning
2018-02-04 Restructure hardwares. IMU init sequence.
2018-02-04 Gyro X readings (seemingly correct)
2018-02-04 Update IMU polling code
2018-02-04 Fix I2C address
2018-02-04 Extend IMU
2018-02-04 Report IMU values
2018-02-05 Try I2CScanResult in proto3
2018-02-05 I2CScanResult became 49B (json) -> 5B(tag+proto). Beware of stack size, buffer[200] crashes command loop.
    [action.hpp, main.cpp]
2018-02-06 Make device scan faster
2018-02-06 More reliable status print
2018-02-07 Get rid of arduino useless code and TWELITE recv w/ async
2018-02-07 Fix critical bug (non-volatile state ends up deleting everything in optimization)
    [main.cpp]
2018-02-07 Further minification of arduino runtime
2018-02-07 Don't report error for invalid packet. Just count them
    [action.hpp]
2018-02-07 Get rid of JSON / print / rich strings / malloc
2018-02-08 Burst sensor read
2018-03-19 Odometry sensor driver
2018-03-19 Bunch of hacks to see odometry sensor reading, to no avail
2018-03-22 Successful X-axis mag reading
2018-04-03 Odometry seems to be working
2018-04-10 Continuous refresh button
2018-04-12 Update fake data & device list
2018-04-29 Copy rail sensor to outpu
2018-05-03 Accumulate odometry reading
2018-05-03 Fix odometry code
